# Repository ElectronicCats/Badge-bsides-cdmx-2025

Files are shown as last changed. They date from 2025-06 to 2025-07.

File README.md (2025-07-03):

# Security BSides CDMX 2025 Badge

## Technology

- Puya PY32F030F28U6TR
- Neopixels
- Display OLED
- 2x AAA Battery Holder
- Shitty Addon Connector

## Getting Started

Your badge comes with a pre-installed firmware, but in case you need to reprogram it, you can use the binaries from the release section.

If you want to build your own firmware, check out the [README](firmware/README.md) in the firmware folder.

## Gratitude
Do you want to say thank you? Tag these companies on social networks and show them your badge, thanks to them it is possible

- [Electronic Cats](https://electroniccats.com/)
- [BSides CDMX](https://bsidescdmx.org/)

## License

Electronic Cats invests time and resources providing this open source design, please support Electronic Cats and open-source hardware by purchasing products from Electronic Cats!

Designed by Electronic Cats.

Hardware released under an CERN Open Hardware Licence v1.2. See the LICENSE_HARDWARE file for more information.

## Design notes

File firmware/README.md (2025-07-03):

# py32f0-template

* Template project for Puya PY32F0 MCU
* Supports GNU Arm Embedded Toolchain
* Supports J-Link and DAPLink/PyOCD programmers
* Supports IDE: VSCode

# Puya PY32F0 Family

PY32F0 are cost-effective Arm Cortex-M0+ microcontrollers featured with wide range operating voltage from 1.7V to 5.5V. Datesheets and Reference Manuals can be found at [WIKI](https://github.com/IOsetting/py32f0-template/wiki).

## PY32F002B

Frequency up to 24 MHz, 24 Kbytes of Flash memory, 3 Kbytes of SRAM.

* PY32F002B
  * PY32F002Bx(24KB Flash/3KB RAM)

## PY32F0xx

Frequency up to 48 MHz, 16 to 64 Kbytes of Flash memory, 3 to 8 Kbytes of SRAM.

* PY32F002A
  * PY32F002Ax5(20KB Flash/3KB RAM)
* PY32F003
  * PY32F003x4(16KB Flash/2KB RAM), PY32F003x6(32KB Flash/4KB RAM), PY32F003x8(64KB Flash/8KB RAM)
* PY32F030
  * PY32F030x4(16KB Flash/2KB RAM), PY32F030x6(32KB Flash/4KB RAM), PY32F030x8(64KB Flash/8KB RAM)

## PY32F07x

Frequency up to 72 MHz, 128 Kbytes of Flash memory, 16 Kbytes of SRAM, with more peripherals(CAN, USB)

* PY32F040
  * PY32F040xB(128KB Flash/16KB RAM)
* PY32F071
  * PY32F071xB(128KB Flash/16KB RAM)
* PY32F072
  * PY32F072xB(128KB Flash/16KB RAM)

# File Structure

```
├── Build                       # Build results
├── Docs                        # Datesheets and User Manuals
├── Examples
│   ├── PY32F002B               # PY32F002B examples
│   │   ├── HAL                 # HAL library examples
│   │   └── LL                  # LL(Low Layer) library examples
│   ├── PY32F07x                # PY32F07x examples
│   │   └── HAL                 # HAL library examples
│   └── PY32F0xx                # PY32F002A,PY32F003,PY32F030 examples
│       ├── FreeRTOS            # FreeRTOS examples
│       ├── HAL                 # HAL library examples
│       └── LL                  # LL(Low Layer) library examples
├── Libraries
│   ├── CMSIS
│   ├── EPaper                  # Waveshare e-paper library
│   ├── FreeRTOS                # FreeRTOS library
│   ├── LDScripts               # LD files
│   ├── PY32F002B_HAL_BSP       # PY32F002B HAL BSP
│   ├── PY32F002B_HAL_Driver    # PY32F002B HAL library
│   ├── PY32F002B_LL_BSP        # PY32F002B LL(low layer) BSP
│   ├── PY32F002B_LL_Driver     # PY32F002B LL library
│   ├── PY32F07x_HAL_BSP        # PY32F040/071/072 HAL BSP
│   ├── PY32F07x_HAL_Driver     # PY32F040/071/072 HAL library
│   ├── PY32F0xx_HAL_BSP        # PY32F002A/003/030 HAL BSP
│   ├── PY32F0xx_HAL_Driver     # PY32F002A/003/030 HAL library
│   ├── PY32F0xx_LL_BSP         # PY32F002A/003/030 LL BSP
│   └── PY32F0xx_LL_Driver      # PY32F002A/003/030 LL library
|
├── Makefile                    # Make config
├── Misc
│   ├── Flash
│   │   ├── JLinkDevices        # JLink flash loaders
│   │   └── Sources             # Flash algorithm source code
│   ├── Puya.PY32F0xx_DFP.x.pack # DFP pack file for PyOCD
│   └── SVD                     # SVD files
├── README.md
├── rules.mk                    # Pre-defined rules include in Makefile 
└── User                        # User application code
```

# Requirements

* PY32F0 EVB or boards of PY32F002/003/030 series
* Programmer
  * J-Link: J-Link OB programmer
  * PyOCD: DAPLink or J-Link
* SEGGER J-Link Software and Documentation pack [https://www.segger.com/downloads/jlink/](https://www.segger.com/downloads/jlink/)
* PyOCD [https://pyocd.io/](https://pyocd.io/)
* GNU Arm Embedded Toolchain

# Building

## 1. Install GNU Arm Embedded Toolchain

Download the toolchain from [Arm GNU Toolchain Downloads](https://developer.arm.com/downloads/-/arm-gnu-toolchain-downloads) according to your pc architecture, extract the files

```bash
sudo mkdir -p /opt/gcc-arm/
sudo tar xvf arm-gnu-toolchain-14.2.rel1-x86_64-arm-none-eabi.tar.xz -C /opt/gcc-arm/
cd /opt/gcc-arm/
sudo chown -R root:root arm-gnu-toolchain-14.2.rel1-x86_64-arm-none-eabi/
```

## 2. Clone This Repository

Clone this repository to local workspace
```bash
git clone https://github.com/IOsetting/py32f0-template.git
```

## 3. Install SEGGER J-Link Or PyOCD

### Option 1: Install SEGGER J-Link

Download and install JLink from [J-Link / J-Trace Downloads](https://www.segger.com/downloads/jlink/).

```bash
# installation command for .deb
sudo dpkg -i JLink_Linux_V784f_x86_64.deb
# uncompression command for .tar.gz
sudo tar xvf JLink_Linux_V784f_x86_64.tgz -C [target folder]
```
The default installation directory is */opt/SEGGER*

Copy [Project directory]/Misc/Flash/JLinkDevices to [User home]/.config/SEGGER/
```bash
cd py32f0-template
cp -r Misc/Flash/JLinkDevices/ ~/.config/SEGGER/
```
Read more: [https://wiki.segger.com/J-Link_Device_Support_Kit](https://wiki.segger.com/J-Link_Device_Support_Kit)

### Option 2: Install PyOCD

Don't install from apt repository, because the version 0.13.1+dfsg-1 is too low for J-Link probe.

Install PyOCD from pip

```bash
pip uninstall pyocd
```
This will install PyOCD into:
```
/home/[user]/.local/bin/pyocd
/home/[user]/.local/bin/pyocd-gdbserver
/home/[user]/.local/lib/python3.10/site-packages/pyocd-0.34.2.dist-info/*
/home/[user]/.local/lib/python3.10/site-packages/pyocd/*
```
In Ubuntu, .profile will take care of the PATH, run `source ~/.profile` to make pyocd command available

## 4. Setup toolchain path

Create a .env file in the firmware root directory, and set the path to the GNU ARM Embedded Toolchain, e.g.

```bash
echo "ARM_TOOLCHAIN=/opt/gcc-arm/arm-gnu-toolchain-14.2.rel1-x86_64-arm-none-eabi/bin" > .env
```

Export the path to your shell environment

```bash
source .env
```

> Remember you have to run `source .env` every time you open a new terminal, or add the line to your shell configuration file, e.g. `~/.bashrc` or `~/.zshrc`.

## 4. Edit Makefile

Change the settings in Makefile

* **MCU_TYPE** The MCU type you are using
* **USE_LL_LIB** Puya provides two sets of library, HAL and LL, set `USE_LL_LIB ?= y` to use LL instead of HAL.
  * No LL Library for PY32F07x
* **ENABLE_PRINTF_FLOAT** set it to `y` to `-u _printf_float` to link options. This will increase the binary size.
* **USE_FREERTOS** Set `USE_FREERTOS ?= y` will include FreeRTOS in compilation
* **USE_DSP** Include CMSIS DSP or not
* **FLASH_PROGRM**
  * If you use J-Link, `FLASH_PROGRM` can be jlink or pyocd
  * If you use DAPLink, set `FLASH_PROGRM ?= pyocd`
  * ST-LINK is not supported yet.
* **ARM_TOOLCHAIN** Make sure it points to the correct path of arm-none-eabi-gcc

```makefile
##### Project #####

PROJECT			?= app
# The path for generated files
BUILD_DIR		= Build

# MCU types: 
#   PY32F002Ax5
#   PY32F002Bx5
#   PY32F003x6, PY32F003x8, 
#   PY32F030x6, PY32F030x8, 
#   PY32F072xB
MCU_TYPE		= PY32F072xB

##### Options #####

# Use LL library instead of HAL, y:yes, n:no
USE_LL_LIB        ?= n
# Enable printf float %f support, y:yes, n:no
ENABLE_PRINTF_FLOAT ?= n
# Build with FreeRTOS, y:yes, n:no
USE_FREERTOS      ?= n
# Build with CMSIS DSP functions, y:yes, n:no
USE_DSP           ?= n
# Programmer, jlink or pyocd
FLASH_PROGRM      ?= pyocd

##### Toolchains #######
ARM_TOOLCHAIN     ?= /usr/bin

# path to JLinkExe
JLINKEXE		?= /opt/SEGGER/JLink/JLinkExe
# path to PyOCD
PYOCD_EXE		?= pyocd
```

## 5. Compiling And Flashing

```bash
# clean source code
make clean
# build
make
# or make with verbose output
V=1 make
# flash
make flash
```

# Debugging In VSCode

Install Cortex Debug extension, add a new configuration in launch.json, e.g.
```
{
    "armToolchainPath": "/opt/gcc-arm/arm-gnu-toolchain-14.2.rel1-x86_64-arm-none-eabi/bin/",
    "toolchainPrefix": "arm-none-eabi",
    "name": "Cortex Debug",
    "cwd": "${workspaceFolder}",
    "executable": "${workspaceFolder}/Build/app.elf",
    "request": "launch",        // can be launch or attach
    "type": "cortex-debug",
    "runToEntryPoint": "Reset_Handler", // "main" or other function name. runToMain is deprecated
    "servertype": "jlink",  // jlink, openocd, pyocd, pe and stutil
    "device": "PY32F030X8",
    "interface": "swd",
    "preLaunchTask": "build",  // Set this to run a task from tasks.json before starting a debug session
    // "preLaunchCommands": ["Build all"], // Uncomment this if not using preLaunchTask
    "svdFile": "${workspaceFolder}/Misc/SVD/py32f030xx.svd",  // svd for this part number
    "showDevDebugOutput": "vscode", // parsed, raw, vscode:vscode log and raw
    "swoConfig":
    {
        "enabled": true,
        "cpuFrequency": 8000000, // Target CPU frequency in Hz
        "swoFrequency":  4000000,
        "source": "probe", // either be “probe” to get directly from the debug probe, 
                           // or a serial port device to use a serial port external to the debug probe.
        "decoders":
        [
            {
                "label": "ITM port 0 output",
                "type": "console",
                "port": 0,
                "showOnStartup": true,
                "encoding": "ascii"
            }
        ]
    }
}
```
If Cortex Debug cannot find JLinkGDBServerCLExe, add the following line to settings.json
```
"cortex-debug.JLinkGDBServerPath": "/opt/SEGGER/JLink/JLinkGDBServerCLExe",
```

# Try Other Examples

More examples can be found in *Examples* folder, copy and replace the files under *User* folder to try different examples.

# Links

* Puya Product Page(Datasheet download): https://www.puyasemi.com/mcu_weichuliqi.html

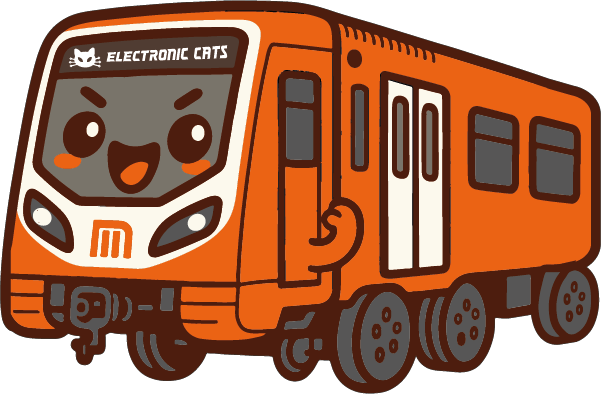
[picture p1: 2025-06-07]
hardware/Metro-Addon/Sources/VAGONCITO_DE_METRO_Mesa_de_trabajo_1.png

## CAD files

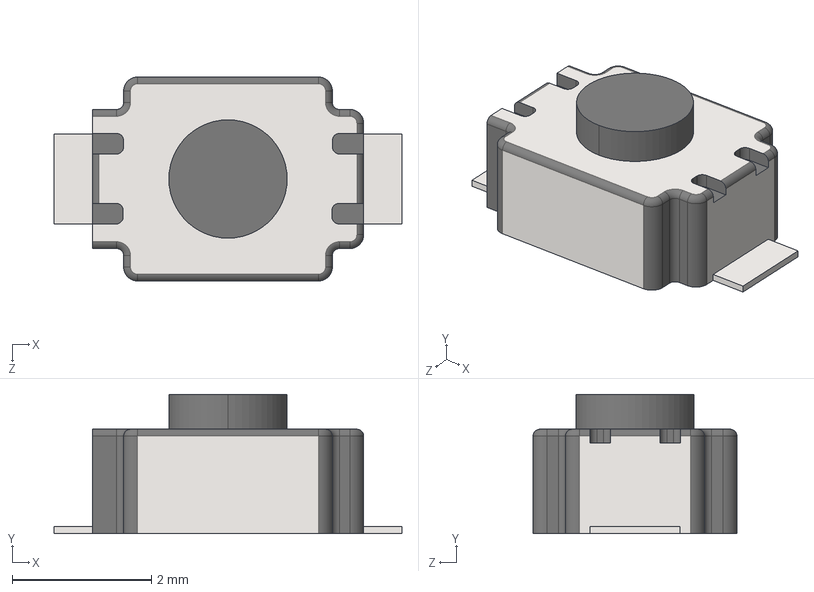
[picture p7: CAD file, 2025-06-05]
hardware/Badge-bsides-cdmx-2025-community/3D/TS-1088R-02526.STEP
5.00 x 2.00 x 2.93 mm

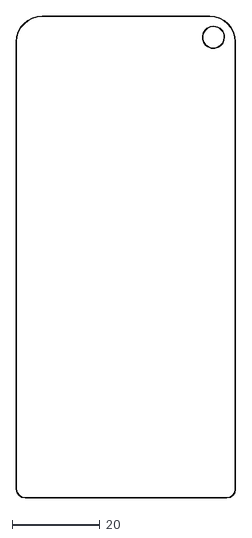
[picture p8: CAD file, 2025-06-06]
hardware/Badge-bsides-cdmx-2025-community/Footprints/CONTORNO-BSIDESCDMX2025.dxf
49.9 x 109.8

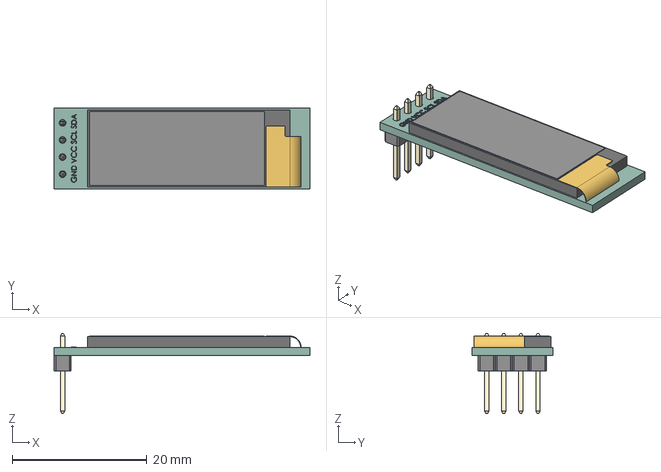
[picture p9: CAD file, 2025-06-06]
hardware/Badge-bsides-cdmx-2025-guest/3D/128x32-OLED.STEP
38.0 x 12.0 x 11.9 mm

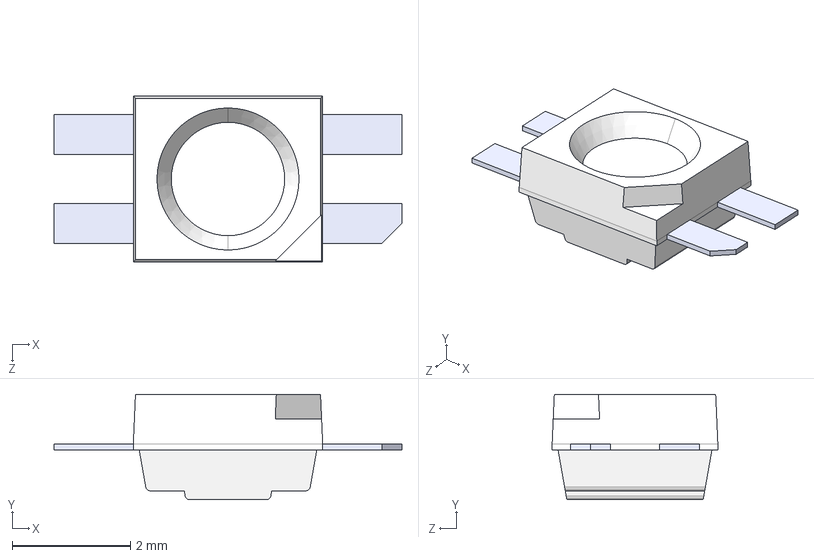
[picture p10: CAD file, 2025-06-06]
hardware/Badge-bsides-cdmx-2025-staff/3D/SK6812-E.step
5.88 x 1.78 x 2.80 mm

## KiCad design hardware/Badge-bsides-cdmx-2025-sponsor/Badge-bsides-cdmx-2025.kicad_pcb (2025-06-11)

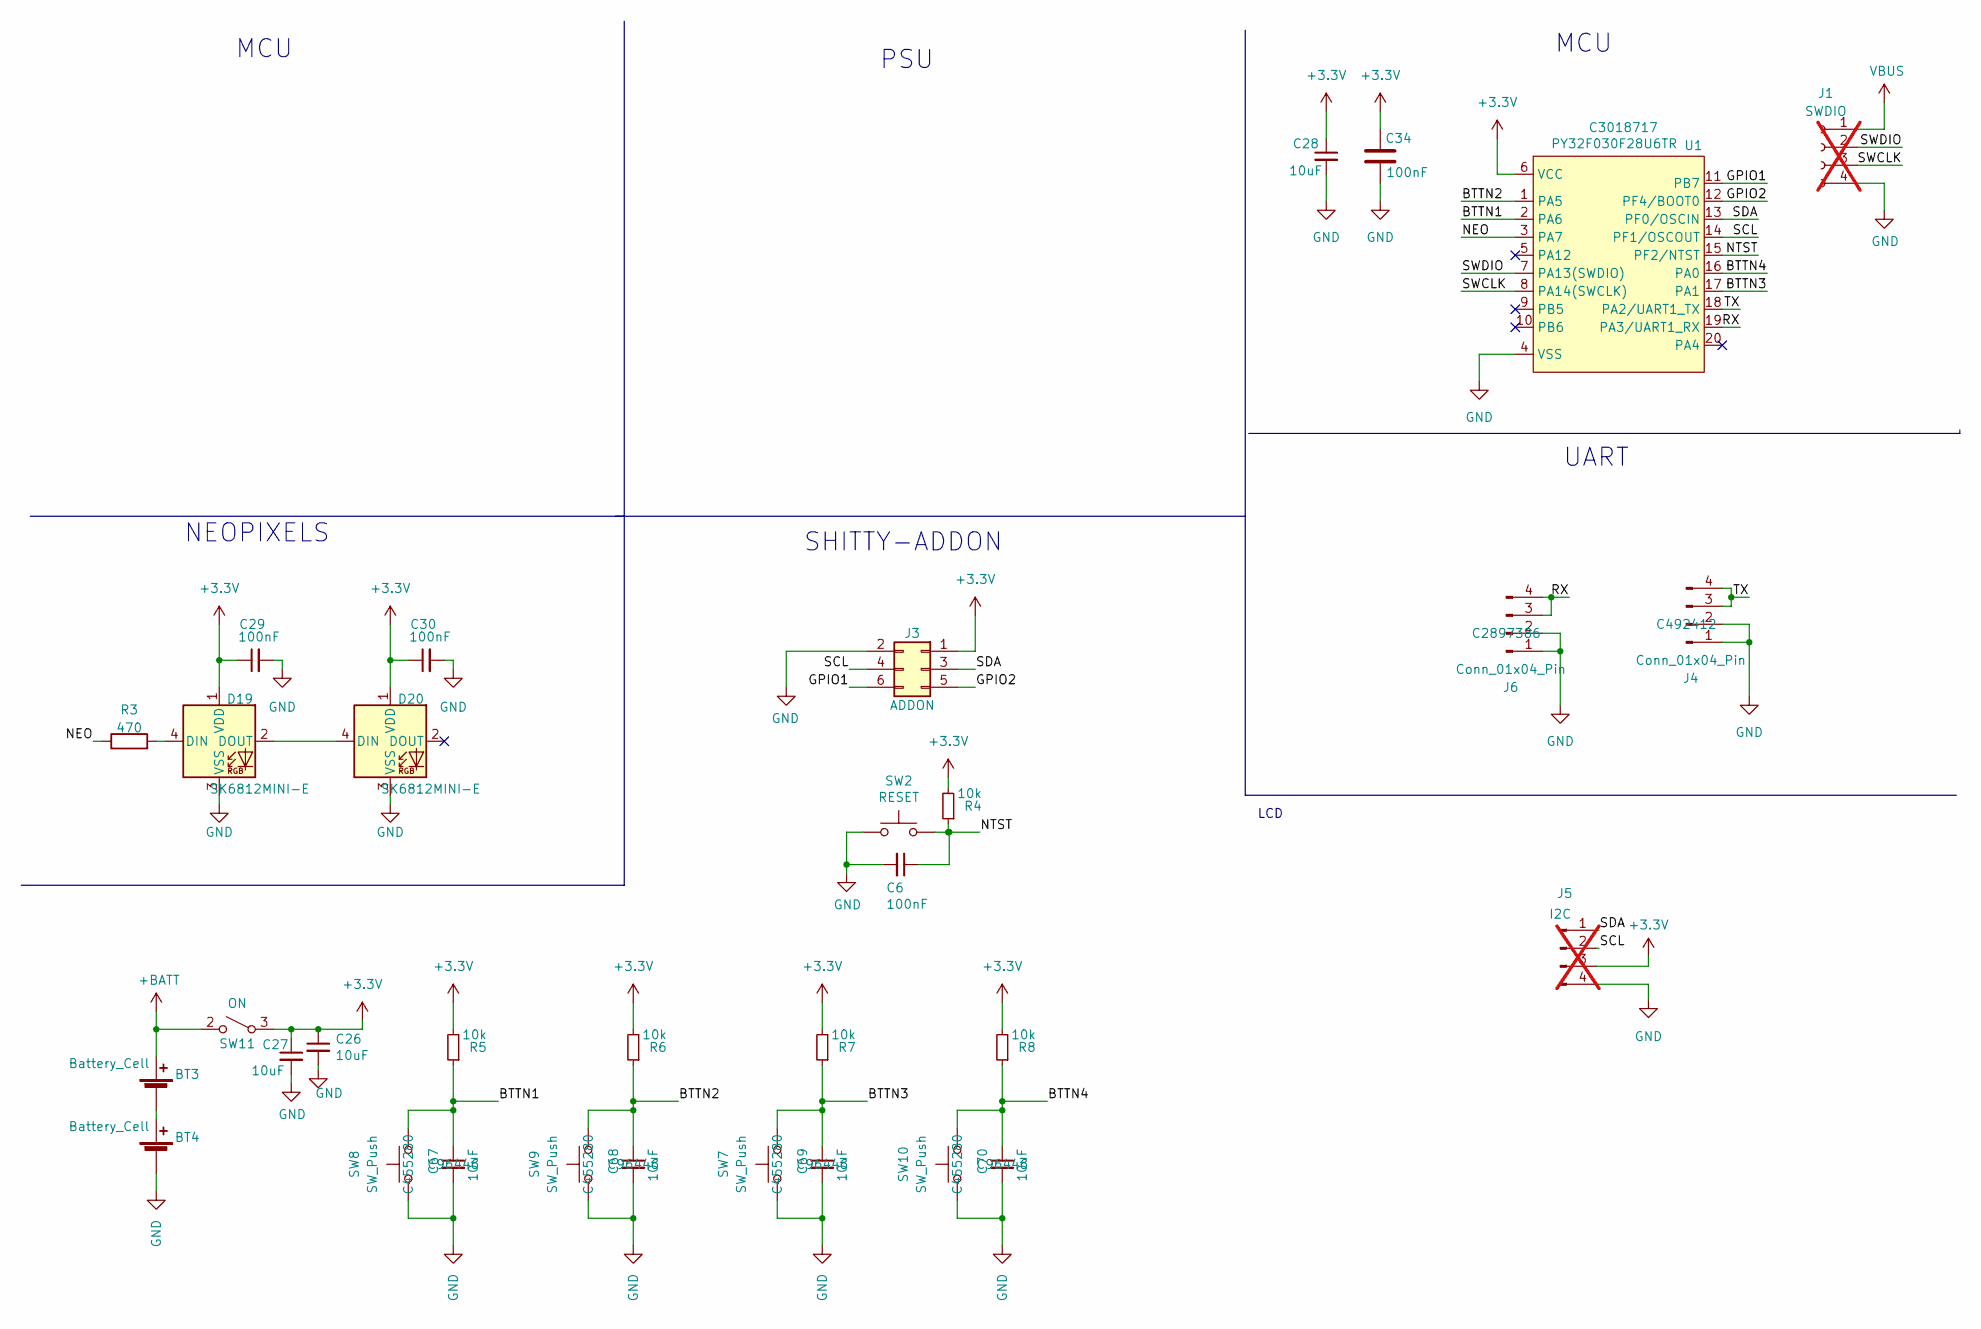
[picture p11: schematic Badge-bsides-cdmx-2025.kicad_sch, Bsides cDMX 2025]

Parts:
BT3, BT4: Battery_Cell; BatteryHolder_Keystone_2466_1xAAA; LCSC# C5290189
C6, C29, C30, C34: 100nF; C_0603_1608Metric; LCSC# C66501
C26, C27, C28, C67, C68, C69, C70: 10uF; C_0603_1608Metric; LCSC# C96446
D19, D20: SK6812MINI-E; LED_SK6812-E; LCSC# C5149201
J1: SWDIO; PinHeader_1x04_P2.54mm_Vertical; not fitted
J3: ADDON; PinSocket_2x03_P2.54mm_Vertical_SMD; LCSC# C3975148
J4: Conn_01x04_Pin; PinHeader_1x04_P2.54mm_Horizontal; LCSC# C492412
J5: I2C; PinSocket_1x04_P2.54mm_Vertical; not fitted
J6: Conn_01x04_Pin; PinSocket_1x04_P2.54mm_Horizontal; LCSC# C2897386
R3: 470; R_0603_1608Metric; LCSC# C114669
R4, R5, R6, R7, R8: 10k; R_0603_1608Metric; LCSC# C99198
SW2: RESET; SW_SPST_TL3342; LCSC# C318884
SW7, SW8, SW9, SW10: SW_Push; TS1088R02026; LCSC# C455280
SW11: ON; JS102011SAQN; LCSC# C221660
U1: PY32F030F28U6TR; QFN-20-1EP_3x3mm_P0.4mm_EP1.65x1.65mm_ThermalVias; LCSC# C3018717

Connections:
+3.3V: C26.1, C27.1, C28.1, C29.1, C30.1, C34.1, D19.1 (VDD), D20.1 (VDD), J3.1, J5.3, R4.2, R5.2, R6.2, R7.2, R8.2, SW11.3 (A), U1.6 (VCC)
+BATT: BT3.2 (+), SW11.2 (B)
/BTTN1: C67.1, R5.1, SW8.2, U1.2 (PA6)
/BTTN2: C68.1, R6.1, SW9.2, U1.1 (PA5)
/BTTN3: C69.1, R7.1, SW7.2, U1.17 (PA1)
/BTTN4: C70.1, R8.1, SW10.2, U1.16 (PA0)
/GPIO1: J3.6, U1.11 (PB7)
/GPIO2: J3.5, U1.12 (PF4/BOOT0)
/NEO: R3.1, U1.3 (PA7)
/NTST: C6.1, R4.1, SW2.2, U1.15 (PF2/NTST)
/RX: J6.3, J6.4, U1.19 (PA3/UART1_RX)
/SCL: J3.4, J5.2, U1.14 (PF1/OSCOUT)
/SDA: J3.3, J5.1, U1.13 (PF0/OSCIN)
/SWCLK: J1.3, U1.8 (PA14(SWCLK))
/SWDIO: J1.2, U1.7 (PA13(SWDIO))
/TX: J4.3, J4.4, U1.18 (PA2/UART1_TX)
GND: BT4.2 (-), C6.2, C26.2, C27.2, C28.2, C29.2, C30.2, C34.2, C67.2, C68.2, C69.2, C70.2, D19.3 (VSS), D20.3 (VSS), J1.4, J3.2, J4.1, J4.2, J5.4, J6.1, J6.2, SW2.1, SW7.1, SW8.1, SW9.1, SW10.1, U1.4 (VSS), U1.21 (VSS)
unnamed: BT3.1 (-), BT4.1 (+)
unnamed: D19.4 (DIN), R3.2
unnamed: D19.2 (DOUT), D20.4 (DIN)
VBUS: J1.1

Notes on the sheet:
LCD
SHITTY-ADDON
MCU
UART
PSU
NEOPIXELS

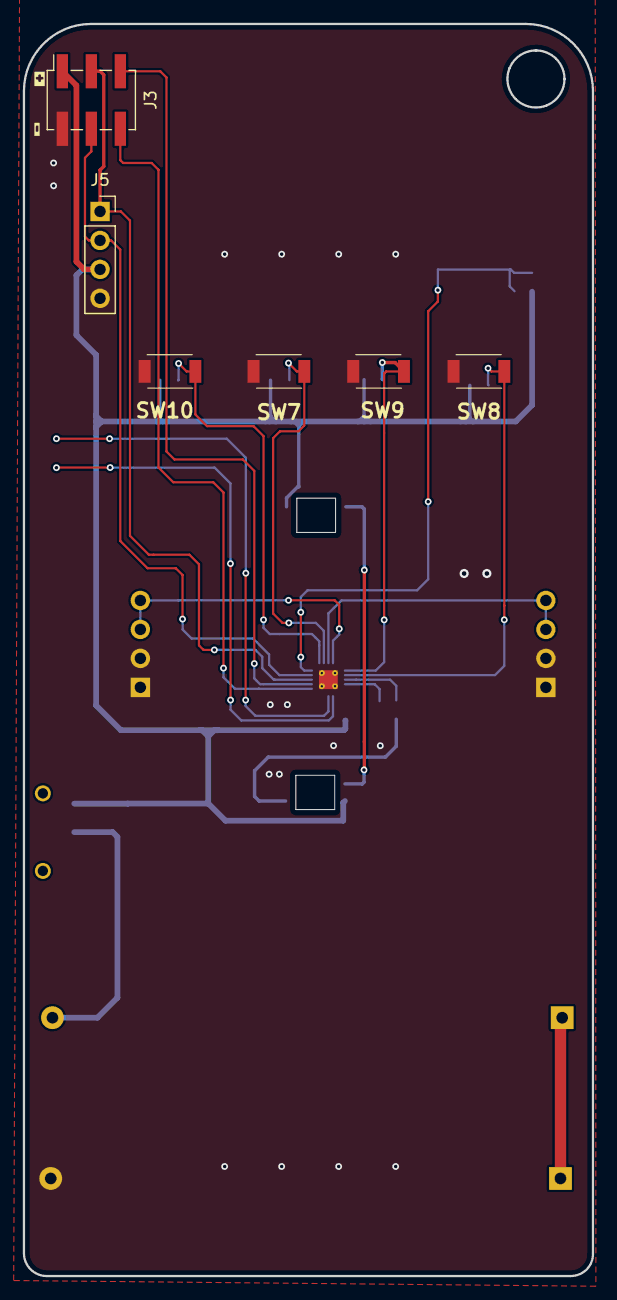
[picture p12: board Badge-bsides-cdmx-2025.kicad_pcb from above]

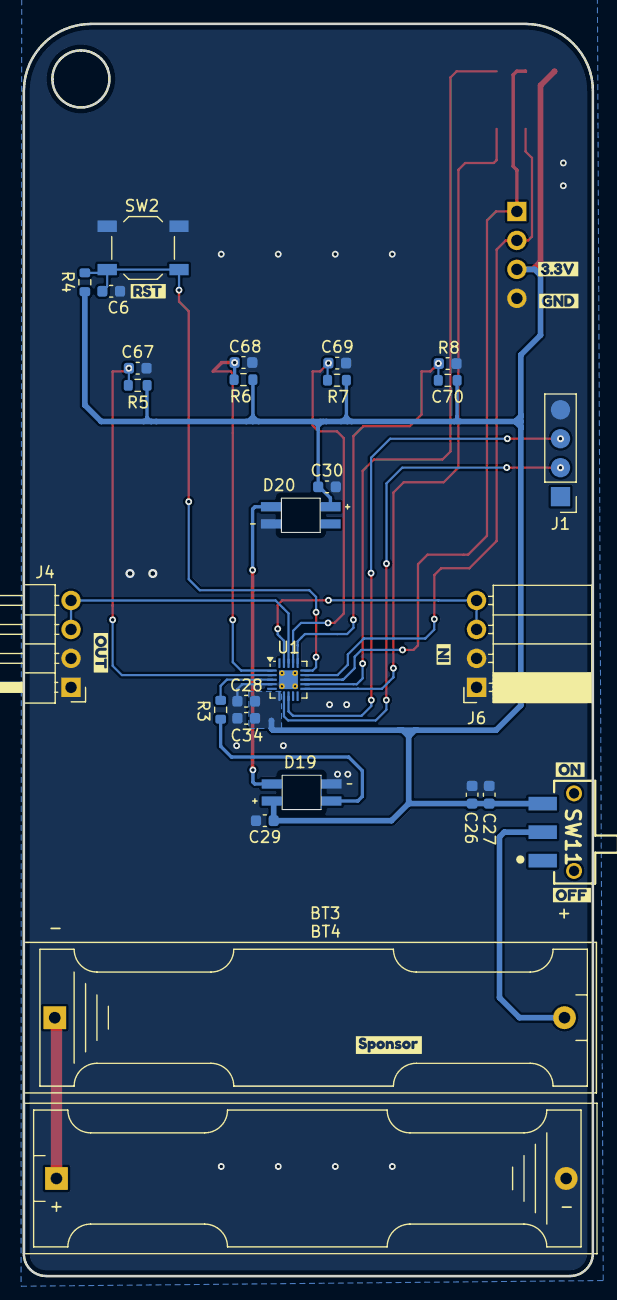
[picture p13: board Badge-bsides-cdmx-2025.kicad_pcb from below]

Board: 2 copper layers, 49.9 x 109.8 mm, 43 parts (35 on the bottom side), 20 nets.

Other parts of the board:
kibuzzard-6841DC13: G***; kibuzzard-6841DC13
kibuzzard-6842C085: G***; kibuzzard-6842C085
kibuzzard-6842ED2D: G***; kibuzzard-6842ED2D
kibuzzard-6842ED45: G***; kibuzzard-6842ED45
kibuzzard-6842EE28: G***; kibuzzard-6842EE28
kibuzzard-6842EE36: G***; kibuzzard-6842EE36
kibuzzard-684316B7: G***; kibuzzard-684316B7
kibuzzard-684316C2: G***; kibuzzard-684316C2
kibuzzard-684316CB: G***; kibuzzard-684316CB
kibuzzard-684316D5: G***; kibuzzard-684316D5

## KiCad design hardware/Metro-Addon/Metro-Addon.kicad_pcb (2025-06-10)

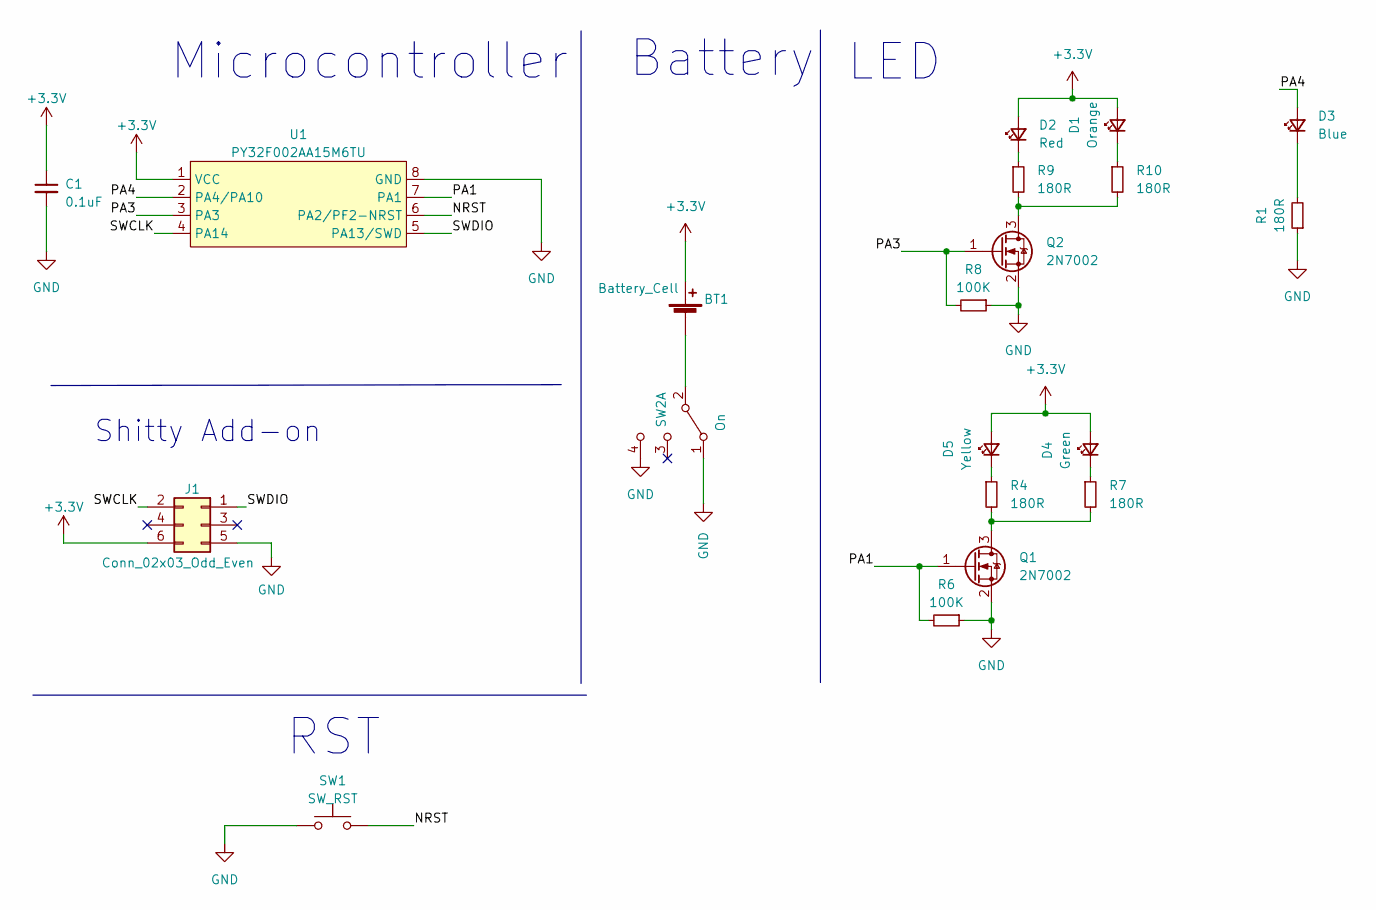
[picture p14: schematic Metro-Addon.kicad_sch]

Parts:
BT1: Battery_Cell; BAT-HLD-001; LCSC# C964833
C1: 0.1uF; C_0805_2012Metric; LCSC# C235731
D1: Orange; LED_0805_2012Metric; LCSC# C434437
D2: Red; LED_0805_2012Metric; LCSC# C965812
D3: Blue; LED_0805_2012Metric; LCSC# C205441
D4: Green; LED_0805_2012Metric; LCSC# C965815
D5: Yellow; LED_0805_2012Metric; LCSC# C84261
J1: Conn_02x03_Odd_Even; B-2100N06P-B111_CKM; LCSC# C780054
Q1, Q2: 2N7002; SOT-23; LCSC# C8545
R1, R4, R7, R9, R10: 180R; R_0805_2012Metric; LCSC# C1339
R6, R8: 100K; R_0805_2012Metric; LCSC# C96346
SW1: SW_RST; SW_SPST_TL3342; LCSC# C318889
SW2: On; MSK12C02; LCSC# C431540
U1: PY32F002AA15M6TU; PY32F002AL15S6TU; LCSC# C5292060

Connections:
+3.3V: BT1.2 (+), C1.1, D1.2 (A), D2.2 (A), D4.2 (A), D5.2 (A), J1.6, U1.1 (VCC)
/NRST: SW1.2, U1.6 (PA2/PF2-NRST)
/PA1: Q1.1 (G), R6.2, U1.7 (PA1)
/PA3: Q2.1 (G), R8.2, U1.3 (PA3)
/PA4: D3.2 (A), U1.2 (PA4/PA10)
/SWCLK: J1.2, U1.4 (PA14)
/SWDIO: J1.1, U1.5 (PA13/SWD)
GND: C1.2, J1.5, Q1.2 (S), Q2.2 (S), R1.1, R6.1, R8.1, SW1.1, SW2.1 (A), SW2.4 (C), U1.8 (GND)
unnamed: BT1.1 (-), SW2.2 (B)
unnamed: D1.1 (K), R10.1
unnamed: D2.1 (K), R9.1
unnamed: D3.1 (K), R1.2
unnamed: D4.1 (K), R7.1
unnamed: D5.1 (K), R4.1
unnamed: Q1.3 (D), R4.2, R7.2
unnamed: Q2.3 (D), R9.2, R10.2

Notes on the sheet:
Microcontroller
LED
RST
Battery
Shitty Add-on

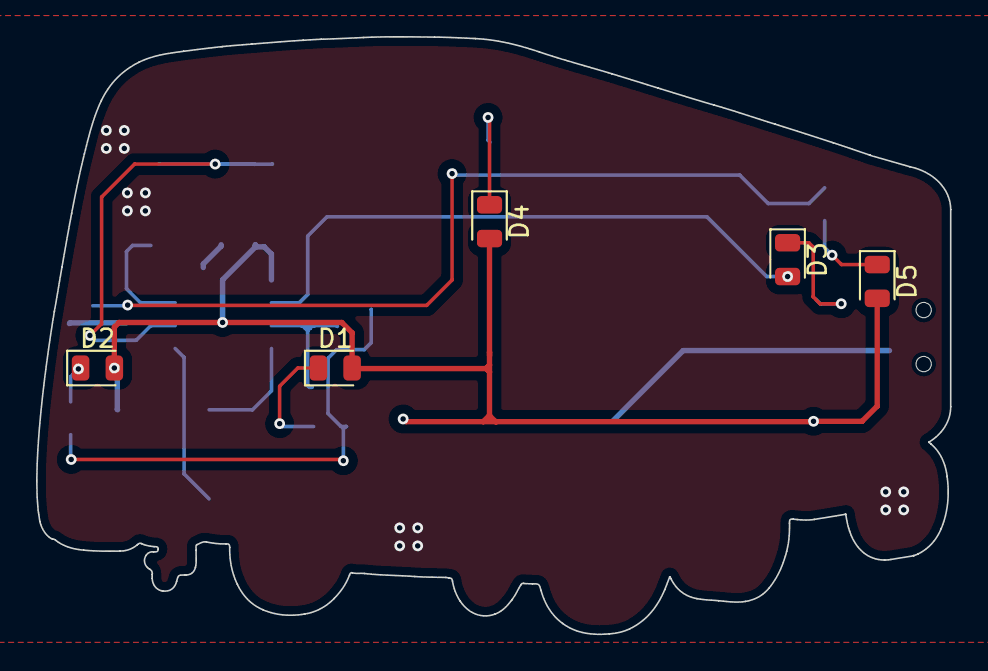
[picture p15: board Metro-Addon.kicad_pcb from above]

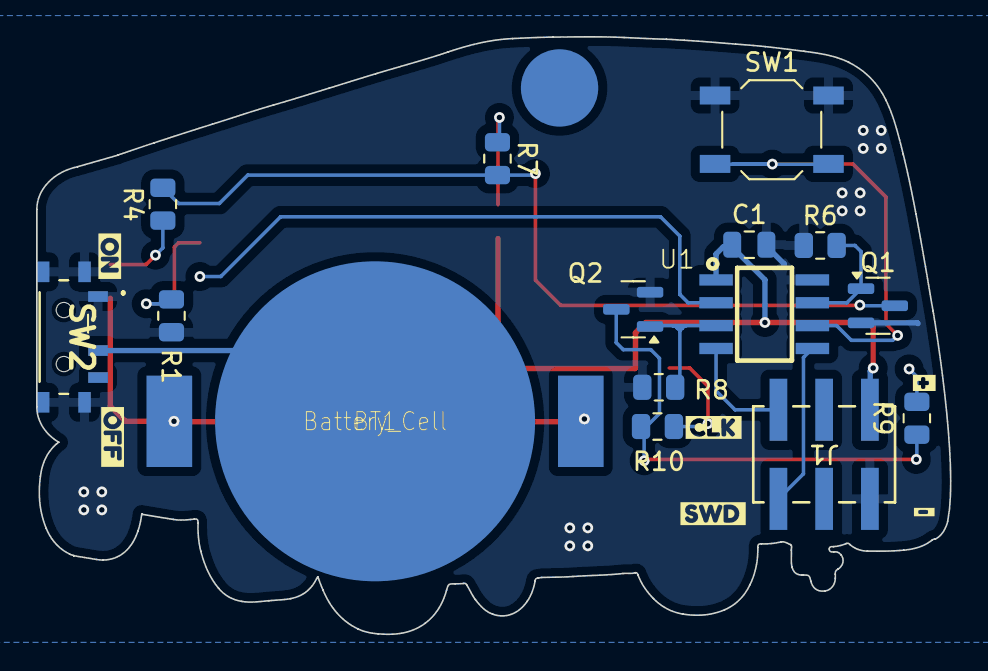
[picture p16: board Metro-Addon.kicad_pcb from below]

Board: 2 copper layers, 50.8 x 33.2 mm, 26 parts (21 on the bottom side), 16 nets.

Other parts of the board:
kibuzzard-684752D8: G***; kibuzzard-684752D8
kibuzzard-684752FB: G***; kibuzzard-684752FB
kibuzzard-684756AF: G***; kibuzzard-684756AF
kibuzzard-684756BD: G***; kibuzzard-684756BD
kibuzzard-684756E4: G***; kibuzzard-684756E4
kibuzzard-684756F0: G***; kibuzzard-684756F0

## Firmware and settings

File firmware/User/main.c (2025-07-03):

/***
 * Demo: I2C - SSD1306 OLED
 *
 * PY32          SSD1306
 *  PF1/PA9       SCL
 *  PF0/PA10      SDA
 */
#include "main.h"
#include <string.h>
#include "bitmaps.h"
#include "buttons.h"
#include "menu.h"
#include "py32f0xx_bsp_clock.h"
#include "py32f0xx_bsp_printf.h"
#include "ssd1306.h"
#include "ws2812_spi.h"

#define I2C_ADDRESS 0xA0 /* host/client address */
#define I2C_STATE_READY 0
#define I2C_STATE_BUSY_TX 1
#define I2C_STATE_BUSY_RX 2

__IO uint32_t i2cState = I2C_STATE_READY;

static void APP_I2C_Config(void);
static void APP_GPIO_Config(void);
static void APP_SPIConfig(void);

int main(void) {
  uint8_t i = 0, r = 0, g = 0x60, b = 0xC0;
  BSP_RCC_HSI_24MConfig();

  BSP_USART_Config(115200);
  printf("I2C Demo: \r\nClock: %ld\r\n", SystemCoreClock);

  APP_I2C_Config();
  APP_GPIO_Config();
  APP_SPIConfig();

  uint8_t res = SSD1306_Init();
  printf("OLED init: %s\n", res == 0 ? "ERROR" : "OK");

  SSD1306_UpdateScreen();
  SSD1306_DrawBitmap(epd_bitmap_bsides_logo, 0, 0, 128, 32);
  SSD1306_UpdateScreen();

  // Wait for any button press
  while (1) {
    if (is_btn_back_pressed()) {
      break;
    }
    if (is_btn_enter_pressed()) {
      break;
    }
    if (is_btn_down_pressed()) {
      break;
    }
    if (is_btn_up_pressed()) {
      break;
    }
    i = (i + 1) % WS2812_NUM_LEDS;
    ws2812_pixel(i, r++, g++, b++);
    LL_mDelay(10);
  }
  
  while (1) {
    Menu_UpdateAndRender();
  }
}

static void APP_GPIO_Config(void) {
  LL_GPIO_InitTypeDef GPIO_InitStruct = {0};

  LL_IOP_GRP1_EnableClock(LL_IOP_GRP1_PERIPH_GPIOA);

  /*
   * Buttons:
   * DOWN:  PA0
   * UP:    PA1
   * BACK:  PA5
   * ENTER: PA6
   */
  GPIO_InitStruct.Pin = LL_GPIO_PIN_0 | LL_GPIO_PIN_1 | LL_GPIO_PIN_5 | LL_GPIO_PIN_6;
  GPIO_InitStruct.Mode = LL_GPIO_MODE_INPUT;
  GPIO_InitStruct.Pull = LL_GPIO_PULL_UP;
  LL_GPIO_Init(GPIOA, &GPIO_InitStruct);
}

static void APP_I2C_Config(void) {
  LL_GPIO_InitTypeDef GPIO_InitStruct = {0};

  LL_IOP_GRP1_EnableClock(LL_IOP_GRP1_PERIPH_GPIOF);
  LL_APB1_GRP1_EnableClock(LL_APB1_GRP1_PERIPH_I2C1);

  /**
   * SCL: PF1 & AF_12, PA9 & AF_6
   * SDA: PF0 & AF_12, PA10 & AF_6
   *
   * Change pins to PF1 / PF0 for parts have no PA9 / PA10
   */
  // PF1 SCL
  GPIO_InitStruct.Pin = LL_GPIO_PIN_1;
  GPIO_InitStruct.Mode = LL_GPIO_MODE_ALTERNATE;
  GPIO_InitStruct.Speed = LL_GPIO_SPEED_FREQ_HIGH;
  GPIO_InitStruct.OutputType = LL_GPIO_OUTPUT_OPENDRAIN;
  GPIO_InitStruct.Pull = LL_GPIO_PULL_UP;
  GPIO_InitStruct.Alternate = LL_GPIO_AF_12;
  LL_GPIO_Init(GPIOF, &GPIO_InitStruct);

  // PF0 SDA
  GPIO_InitStruct.Pin = LL_GPIO_PIN_0;
  GPIO_InitStruct.Alternate = LL_GPIO_AF_12;
  LL_GPIO_Init(GPIOF, &GPIO_InitStruct);

  LL_APB1_GRP1_ForceReset(LL_APB1_GRP1_PERIPH_I2C1);
  LL_APB1_GRP1_ReleaseReset(LL_APB1_GRP1_PERIPH_I2C1);

  LL_I2C_InitTypeDef I2C_InitStruct;
  /*
   * Clock speed:
   * - standard = 100khz, if PLL is on, set system clock <= 16MHz, or i2c cannot work normally
   * - fast     = 400khz
   */
  I2C_InitStruct.ClockSpeed = LL_I2C_MAX_SPEED_FAST;
  I2C_InitStruct.DutyCycle = LL_I2C_DUTYCYCLE_16_9;
  I2C_InitStruct.OwnAddress1 = I2C_ADDRESS;
  I2C_InitStruct.TypeAcknowledge = LL_I2C_NACK;
  LL_I2C_Init(I2C1, &I2C_InitStruct);

  /* Enale clock stretch (reset default: on) */
  // LL_I2C_EnableClockStretching(I2C1);

  /* Enable general call (reset default: off) */
  // LL_I2C_EnableGeneralCall(I2C1);
}

void APP_I2C_Transmit(uint8_t devAddress, uint8_t memAddress, uint8_t* pData, uint16_t len) {
  while (i2cState == I2C_STATE_BUSY_TX)
    ;

  LL_I2C_DisableBitPOS(I2C1);

  i2cState = I2C_STATE_BUSY_TX;

  /* Start */
  LL_I2C_GenerateStartCondition(I2C1);
  while (LL_I2C_IsActiveFlag_SB(I2C1) != 1)
    ;
  /* Send slave address */
  LL_I2C_TransmitData8(I2C1, (devAddress & (uint8_t)(~0x01)));
  while (LL_I2C_IsActiveFlag_ADDR(I2C1) != 1)
    ;
  LL_I2C_ClearFlag_ADDR(I2C1);

  /* Send memory address */
  LL_I2C_TransmitData8(I2C1, memAddress);
  while (LL_I2C_IsActiveFlag_BTF(I2C1) != 1)
    ;

  /* Transfer data */
  while (len > 0) {
    while (LL_I2C_IsActiveFlag_TXE(I2C1) != 1)
      ;
    LL_I2C_TransmitData8(I2C1, *pData++);
    len--;

    if ((LL_I2C_IsActiveFlag_BTF(I2C1) == 1) && (len != 0U)) {
      LL_I2C_TransmitData8(I2C1, *pData++);
      len--;
    }

    while (LL_I2C_IsActiveFlag_BTF(I2C1) != 1)
      ;
  }

  /* Stop */
  LL_I2C_GenerateStopCondition(I2C1);
  i2cState = I2C_STATE_READY;
}

uint8_t SPI_TxRxByte(uint8_t data)
{
  uint8_t SPITimeout = 0xFF;
  /* Check the status of Transmit buffer Empty flag */
  while (READ_BIT(SPI1->SR, SPI_SR_TXE) == RESET)
  {
    if (SPITimeout-- == 0) return 0;
  }
  LL_SPI_TransmitData8(SPI1, data);
  SPITimeout = 0xFF;
  while (READ_BIT(SPI1->SR, SPI_SR_RXNE) == RESET)
  {
    if (SPITimeout-- == 0) return 0;
  }
  // Read from RX buffer
  return LL_SPI_ReceiveData8(SPI1);
}

static void APP_SPIConfig(void)
{
  LL_SPI_InitTypeDef SPI_InitStruct = {0};
  LL_GPIO_InitTypeDef GPIO_InitStruct = {0};

  LL_IOP_GRP1_EnableClock(LL_IOP_GRP1_PERIPH_GPIOA);
  LL_APB1_GRP2_EnableClock(LL_APB1_GRP2_PERIPH_SPI1);

  // PA7 MOSI
  GPIO_InitStruct.Pin = LL_GPIO_PIN_7;
  GPIO_InitStruct.Mode = LL_GPIO_MODE_ALTERNATE;
  GPIO_InitStruct.Speed = LL_GPIO_SPEED_FREQ_HIGH;
  GPIO_InitStruct.OutputType = LL_GPIO_OUTPUT_PUSHPULL;
  GPIO_InitStruct.Pull = LL_GPIO_PULL_NO;
  GPIO_InitStruct.Alternate = LL_GPIO_AF_0;
  LL_GPIO_Init(GPIOA, &GPIO_InitStruct);

  /* The frequency after prescaler should be below 8.25MHz */
  SPI_InitStruct.BaudRate = LL_SPI_BAUDRATEPRESCALER_DIV8;
  SPI_InitStruct.TransferDirection = LL_SPI_FULL_DUPLEX;
  SPI_InitStruct.Mode = LL_SPI_MODE_MASTER;
  SPI_InitStruct.DataWidth = LL_SPI_DATAWIDTH_8BIT;
  SPI_InitStruct.ClockPolarity = LL_SPI_POLARITY_LOW;
  SPI_InitStruct.ClockPhase = LL_SPI_PHASE_1EDGE;
  SPI_InitStruct.NSS = LL_SPI_NSS_SOFT;
  SPI_InitStruct.BitOrder = LL_SPI_MSB_FIRST;
  LL_SPI_Init(SPI1, &SPI_InitStruct);
  LL_SPI_Enable(SPI1);
}

void APP_ErrorHandler(void) {
  while (1)
    ;
}

#ifdef USE_FULL_ASSERT
void assert_failed(uint8_t* file, uint32_t line) {
  while (1)
    ;
}
#endif /* USE_FULL_ASSERT */

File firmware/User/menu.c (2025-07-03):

#include <stdio.h>
#include <string.h>

#include "py32f0xx_bsp_printf.h"
#include "py32f0xx_ll_bus.h"
#include "py32f0xx_ll_gpio.h"
#include "py32f0xx_ll_usart.h"

#include "ascii_fonts.h"
#include "buttons.h"
#include "main.h"
#include "menu.h"
#include "ssd1306.h"
#include "ws2812_spi.h"

static const char* credits_lines[] = {
    "Gracias a los",
    "patrocinadores HSBC",
    "Gracias a Electronic",
    "Cats Team",
    "Hardware: Uri,",
    "Capuchino, Lizeth,",
    "Yoshio y Carlos",
    "Firmware: Francisco",
    " - @deimoshall",
    "",
    "Hecho con amor",
    "desde Mexico"};
#define CREDITS_LINE_COUNT (sizeof(credits_lines) / sizeof(credits_lines[0]))
#define CREDITS_FONT_HEIGHT 10
#define CREDITS_VISIBLE_LINES 3

// Buffer and flags for UART communication
#define UART_BUF_SIZE 128
static uint8_t uart_rx_buf[UART_BUF_SIZE];
static volatile uint8_t uart_rx_flag = 0;
static volatile uint8_t uart_rx_pos = 0;

// Forward declarations for UART listener functions
static void UART_Listener_Init(void);
static void UART_Listener_DeInit(void);
static void UART_Listener_IRQCallback(void);

// Menu actions
static void connect_action();
static void credits_action();
static void settings_action();
static void leds_brightness_action();

typedef enum {
  ANIM_MODE_SOLID,
  ANIM_MODE_RAINBOW,
  ANIM_MODE_MEXICAN_FLAG,
  ANIM_MODE_COUNT
} AnimationMode;

typedef struct {
  AnimationMode mode;
  uint8_t solid_color;  // 0=Red, 1=Green, 2=Blue
} AnimationState;

static AnimationState anim_state = {
    .mode = ANIM_MODE_RAINBOW,
    .solid_color = 0,
};

typedef struct {
  uint8_t r, g, b;
} RGBColor;

#define DEFAULT_COLOR {0, 0x60, 0xC0}

static volatile RGBColor current_color = DEFAULT_COLOR;

static void animation_run() {
  static uint16_t flag_tick_counter = 0;
  static uint8_t flag_phase = 0;  // 0: green, 1: white, 2: red
  const uint16_t flag_update_ticks = 50;

  switch (anim_state.mode) {
    case ANIM_MODE_SOLID: {
      uint8_t r = 0, g = 0, b = 0;
      if (anim_state.solid_color == 0)
        r = 0xFF;
      else if (anim_state.solid_color == 1)
        g = 0xFF;
      else
        b = 0xFF;
      current_color.r = r;
      current_color.g = g;
      current_color.b = b;
      ws2812_pixel_all(current_color.r, current_color.g, current_color.b);
      break;
    }
    case ANIM_MODE_RAINBOW:
      ws2812_pixel_all(current_color.r++, current_color.g++, current_color.b++);
      break;
    case ANIM_MODE_MEXICAN_FLAG: {
      flag_tick_counter++;
      if (flag_tick_counter >= flag_update_ticks) {
        flag_phase = (flag_phase + 1) % 3;
        flag_tick_counter = 0;
      }
      switch (flag_phase) {
        case 0:  // Green
          current_color.r = 0;
          current_color.g = 0xFF;
          current_color.b = 0;
          ws2812_pixel_all(current_color.r, current_color.g, current_color.b);
          break;
        case 1:  // White
          current_color.r = 0xFF;
          current_color.g = 0xFF;
          current_color.b = 0xFF;
          ws2812_pixel_all(current_color.r, current_color.g, current_color.b);
          break;
        case 2:  // Red
          current_color.r = 0xFF;
          current_color.g = 0;
          current_color.b = 0;
          ws2812_pixel_all(current_color.r, current_color.g, current_color.b);
          break;
      }
      break;
    }
    default:
      ws2812_pixel_all(0, 0, 0);
      break;
  }
}

static const char* anim_mode_names[] = {
    "Color",
    "Arcoiris",
    "Bandera"};

static const char* color_names[] = {
    "Rojo",
    "Verde",
    "Azul"};

#define ANIM_MODE_VISIBLE_ITEMS 2

static void select_solid_color_action(void) {
  anim_state.mode = ANIM_MODE_SOLID;
  int8_t color_idx = anim_state.solid_color;
  uint8_t color_render = 1;
  while (1) {
    animation_run();
    if (is_btn_up_pressed()) {
      color_idx = (color_idx + 2) % 3;
      color_render = 1;
    } else if (is_btn_down_pressed()) {
      color_idx = (color_idx + 1) % 3;
      color_render = 1;
    } else if (is_btn_enter_pressed()) {
      anim_state.solid_color = color_idx;
      break;
    } else if (is_btn_back_pressed()) {
      break;
    }
    if (color_render) {
      SSD1306_Fill(SSD1306_COLOR_BLACK);
      SSD1306_UpdateScreen();
      SSD1306_GotoXY(10, 8);
      SSD1306_Puts("Select Color", &Font_6x10, SSD1306_COLOR_WHITE);
      SSD1306_GotoXY(30, 20);
      SSD1306_Puts((char*)color_names[color_idx], &Font_6x10, SSD1306_COLOR_WHITE);
      SSD1306_UpdateScreen();
      color_render = 0;
    }
    LL_mDelay(20);
  }
}

static void set_anim_rainbow_action(void) {
  current_color.r = 0;
  current_color.g = 0x60;
  current_color.b = 0xC0;
  anim_state.mode = ANIM_MODE_RAINBOW;
}

static void set_anim_flag_action(void) {
  anim_state.mode = ANIM_MODE_MEXICAN_FLAG;
}

// Menu item definition
typedef struct {
  const char* name;
  void (*action)(void);
} MenuItem_t;

static const MenuItem_t animMenuItems[] = {
    {"Color", select_solid_color_action},
    {"Arcoiris", set_anim_rainbow_action},
    {"Bandera", set_anim_flag_action},
};
#define ANIM_MENU_ITEM_COUNT (sizeof(animMenuItems) / sizeof(MenuItem_t))
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

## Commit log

2025-06-02 Feat(Hw): SCH_0.1v
    [Badge-bsides-cdmx-2025.kicad_pcb, Badge-bsides-cdmx-2025.kicad_sch]
2025-06-02 FIx(Hw): Fixed_Bom_and_footprints
    [Badge-bsides-cdmx-2025.kicad_pcb, Badge-bsides-cdmx-2025.kicad_sch]
2025-06-03 feat: add button RST and shitty connector
    [Badge-bsides-cdmx-2025.kicad_sch]
2025-06-05 feat(Hw): Floorplan draft
    [Badge-bsides-cdmx-2025.kicad_pcb, Badge-bsides-cdmx-2025.kicad_sch]
2025-06-06 Feat(Hw): Fixed_Bom(Sponsor,guest)
    [Badge-bsides-cdmx-2025.kicad_pcb, Badge-bsides-cdmx-2025.kicad_sch]
2025-06-06 Feat(Hw): FIxed_neopixels_bom(Sponsor,guest)
    [Badge-bsides-cdmx-2025.kicad_sch]
2025-06-06 Auto stash before merge of "main" and "origin/main"
    [128x32-OLED.STEP, Badge-bsides-cdmx-2025.kicad_pcb, Badge-bsides-cdmx-2025.kicad_sch]
2025-06-06 Fix(Hw): Fixed_BOM(Staff,Community, Speaker)
    [Badge-bsides-cdmx-2025.kicad_pcb, Badge-bsides-cdmx-2025.kicad_sch]
2025-06-06 feat:remove usb staff
    [Badge-bsides-cdmx-2025.kicad_sch]
2025-06-06 fix: vbus ok staff
    [Badge-bsides-cdmx-2025.kicad_sch]
2025-06-06 feat(hw): add metro-addon project
    [Metro-Addon.kicad_pcb, Metro-Addon.kicad_sch]
2025-06-06 feat(hw): add schematic in metro-addon
    [Metro-Addon.kicad_sch]
2025-06-07 feat(hw): add routes in metro addon
    [Metro-Addon.kicad_pcb, Metro-Addon.kicad_sch]
2025-06-19 chore: use arm toolchain from env file
2025-06-20 fix: flat content on screen
    [main.c]
2025-06-21 feat: configure navigation buttons
2025-06-24 fix: pressed buttons
2025-06-25 feat: add uart listener
2025-06-25 fix: end of line char
    [menu.c]
2025-06-27 fix: neopixels animation on all menus
    [menu.c]
2025-07-02 fix: unable to turn on leds after turn off
    [menu.c]
2025-07-02 feat: replace breathing by mexican flag animation
    [menu.c]
2025-07-02 fix: syncronize animations across badges
    [menu.c]
2025-07-02 fix: cannot select other animation after selecting solid color
    [menu.c]
2025-07-02 fix: current animation do not work on main menu
    [main.c, menu.c]
2025-07-02 fix: real time brightness control
    [menu.c]
